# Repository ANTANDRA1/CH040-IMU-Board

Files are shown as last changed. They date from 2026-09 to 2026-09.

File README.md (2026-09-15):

ПЛАТА ДЛЯ IMU CH040

ОПИС ПРОЄКТУ

Проєкт являє собою односторонню друковану плату для підключення інерціального модуля CH040 IMU/VRU.

Плата розроблена в KiCad 10.

Основні завдання плати:

- встановлення модуля CH040;
- виведення всіх 18 контактів CH040 на гребінки Dupont з кроком 2.54 мм;
- додаткове виведення робочих інформаційних сигналів на роз'єм JST GH з кроком 1.25 мм;
- забезпечення живлення модуля;
- захист лінії живлення;
- монтажні отвори під гвинти М2.

CH040

CH040 — інерціальний модуль IMU/VRU.

Модуль підтримує UART та CAN-інтерфейси.

Для використання повноцінної CAN-шини необхідний зовнішній CAN-трансивер, оскільки CAN_TX та CAN_RX є логічними сигналами модуля, а не безпосередньо CANH та CANL.

Габарити модуля:

25 × 20 × 2.7 мм

РОЗ'ЄМ J1 — DUPONT 1×9, 2.54 ММ

1 — VDD
2 — GND
3 — EN
4 — IO1
5 — IO2
6 — RXD2
7 — TXD2
8 — GND
9 — IO5

РОЗ'ЄМ J2 — DUPONT 1×9, 2.54 ММ

1 — NRST
2 — RXD3
3 — TXD3
4 — CAN_TX
5 — CAN_RX
6 — IO9
7 — RXD1
8 — TXD1
9 — IO6

Таким чином, на J1 та J2 виведені всі 18 контактів CH040.

РОЗ'ЄМ J3 — JST GH 1×10, 1.25 ММ

На роз'єм J3 виведені робочі інформаційні та керуючі сигнали.

1 — EN
2 — IO1_EXT
3 — IO2_EXT
4 — IO5
5 — IO6
6 — UART1_TX
7 — UART1_RX
8 — CAN_TX
9 — CAN_RX
10 — NRST_EXT

Лінії IO1, IO2, TXD1, RXD1 та NRST підключені до J3 через послідовні резистори 1 кОм.

Контакти RXD2, TXD2, RXD3 та TXD3 не використовуються в поточній конфігурації CH040, а IO9 є зарезервованим, тому вони не дублюються на JST.

ЖИВЛЕННЯ

Живлення плати подається через роз'єм J4.

Робоча напруга:

3.3–5 В

Для захисту лінії живлення використані:

F1 — запобіжник 300 мА
D1 — TVS-діод SMF5.0CA

Схема живлення:

J4 → F1 → VDD → CH040

TVS-діод D1 підключений між VDD та GND.

ПЕРЕМИЧКА GND

Плата виконана односторонньою.

Контакт 8 модуля CH040 є контактом GND.

Через особливості одностороннього трасування його підключення до основної землі виконується через перемичку:

R6 — 0 Ом

Використовується вивідний THT-резистор, який фізично виконує функцію перемички над сигнальними доріжками.

ПОСАДКОВЕ МІСЦЕ CH040

Посадкове місце CH040 створене вручну відповідно до документації виробника.

Основні параметри:

габарит модуля — 25 × 20 мм
розмір контактної площадки — 1.4 × 1.2 мм
основний крок контактів — 2 мм

Під модулем створена спеціальна Keepout-зона.

У цій зоні заборонено:

- прокладати доріжки;
- розміщувати перехідні отвори;
- виконувати заливку міддю.

МОНТАЖ

На платі передбачено чотири монтажні отвори:

H1
H2
H3
H4

Отвори призначені для кріплення плати гвинтами М2.

ОСНОВНІ КОМПОНЕНТИ

U1 — CH040

J1, J2 — Dupont 1×9, 2.54 мм

J3 — JST GH 1×10, 1.25 мм

J4 — роз'єм живлення

R1–R5 — 1 кОм, корпус 0402

R6 — 0 Ом, THT

F1 — 300 мА

D1 — SMF5.0CA

H1–H4 — монтажні отвори М2

СТРУКТУРА ПРОЄКТУ

CH040

KiCad
    Ch040.kicad_pro
    Ch040.kicad_sch
    Ch040.kicad_pcb
    бібліотека символу CH040
    бібліотека посадкового місця CH040

Gerber & Drill
    Gerber-файли
    Drill-файли

Datasheet
    документація CH040

README.txt

ВІДТВОРЕННЯ ПРОЄКТУ

Для відкриття та редагування проєкту рекомендується використовувати KiCad 10.

1. Завантажити або клонувати репозиторій.

2. Відкрити файл Ch040.kicad_pro.

3. Перевірити підключення бібліотеки символу CH040 та бібліотеки його посадкового місця.

4. Відкрити принципову схему.

5. Відкрити PCB.

6. Запустити ERC для перевірки електричної схеми.

7. Запустити DRC для перевірки друкованої плати.

8. Для виробництва використовувати Gerber та Drill-файли з відповідної папки.

ПЕРЕВІРКА ПЛАТИ

Перед формуванням виробничих файлів виконано:

- ERC;
- DRC;
- перевірку нез'єднаних мереж;
- перевірку Keepout-зони CH040;
- перевірку плати у 3D Viewer;
- формування Gerber-файлів;
- формування Drill-файлів.

ПРИМІТКА

Проєкт виконаний відповідно до технічного завдання на розробку плати для IMU CH040.

Репозиторій містить принципову схему, PCB, користувацькі бібліотеки, Gerber-файли, файли свердління та документацію, необхідну для відтворення плати.

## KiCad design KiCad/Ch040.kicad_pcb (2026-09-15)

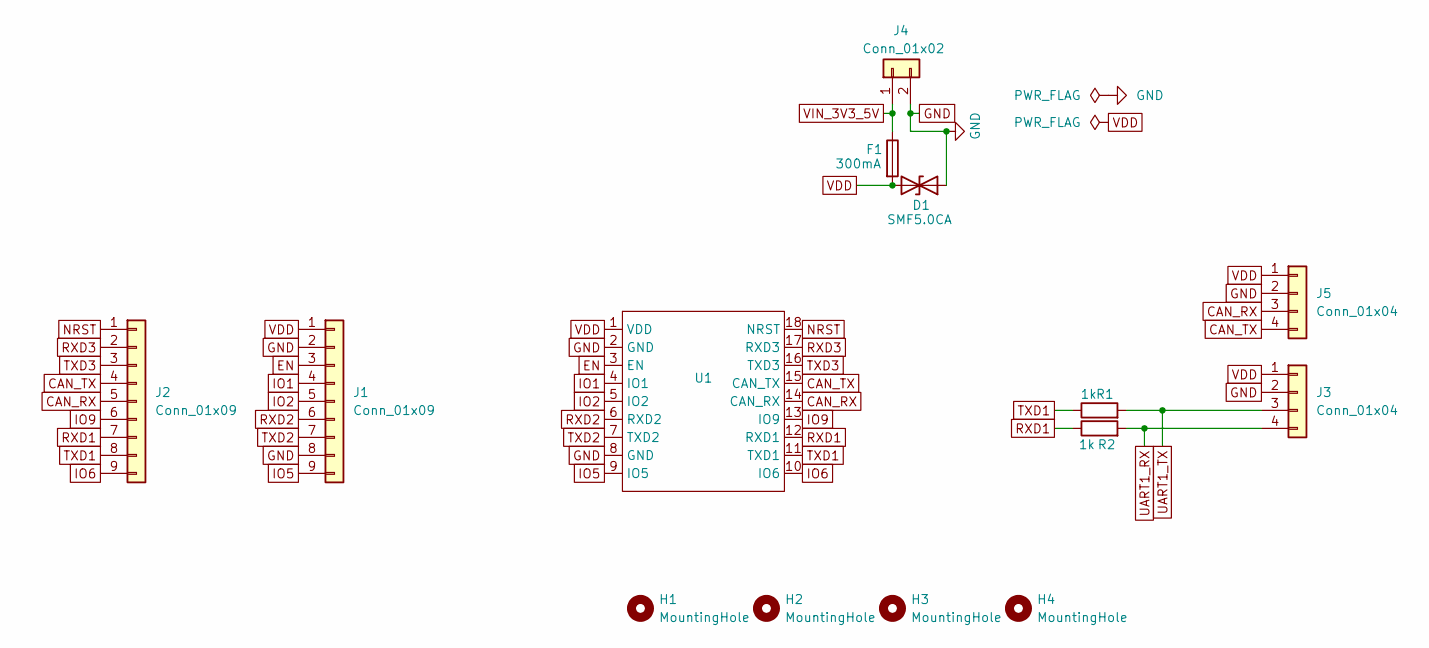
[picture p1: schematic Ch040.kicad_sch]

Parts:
D1: SMF5.0CA; D_SMA
F1: 300mA; Fuse_0603_1608Metric
H1, H2, H3, H4: MountingHole; MountingHole_2.2mm_M2
J1, J2: Conn_01x09; PinHeader_1x09_P2.54mm_Vertical
J3, J5: Conn_01x04; JST_GH_SM04B-GHS-TB_1x04-1MP_P1.25mm_Horizontal
J4: Conn_01x02; PinSocket_1x02_P2.54mm_Vertical
R1, R2: 1k; R_0805_2012Metric
U1: CH040

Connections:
CAN_RX: J2.5, J5.3, U1.14 (CAN_RX)
CAN_TX: J2.4, J5.4, U1.15 (CAN_TX)
EN: J1.3, U1.3 (EN)
GND: D1.1 (A1), J1.2, J1.8, J3.2, J4.2, J5.2, U1.2 (GND), U1.8 (GND)
IO1: J1.4, U1.4 (IO1)
IO2: J1.5, U1.5 (IO2)
IO5: J1.9, U1.9 (IO5)
IO6: J2.9, U1.10 (IO6)
IO9: J2.6, U1.13 (IO9)
NRST: J2.1, U1.18 (NRST)
RXD1: J2.7, R2.1, U1.12 (RXD1)
RXD2: J1.6, U1.6 (RXD2)
RXD3: J2.2, U1.17 (RXD3)
TXD1: J2.8, R1.1, U1.11 (TXD1)
TXD2: J1.7, U1.7 (TXD2)
TXD3: J2.3, U1.16 (TXD3)
UART1_RX: J3.4, R2.2
UART1_TX: J3.3, R1.2
VDD: D1.2 (A2), F1.2, J1.1, J3.1, J5.1, U1.1 (VDD)
VIN_3V3_5V: F1.1, J4.1

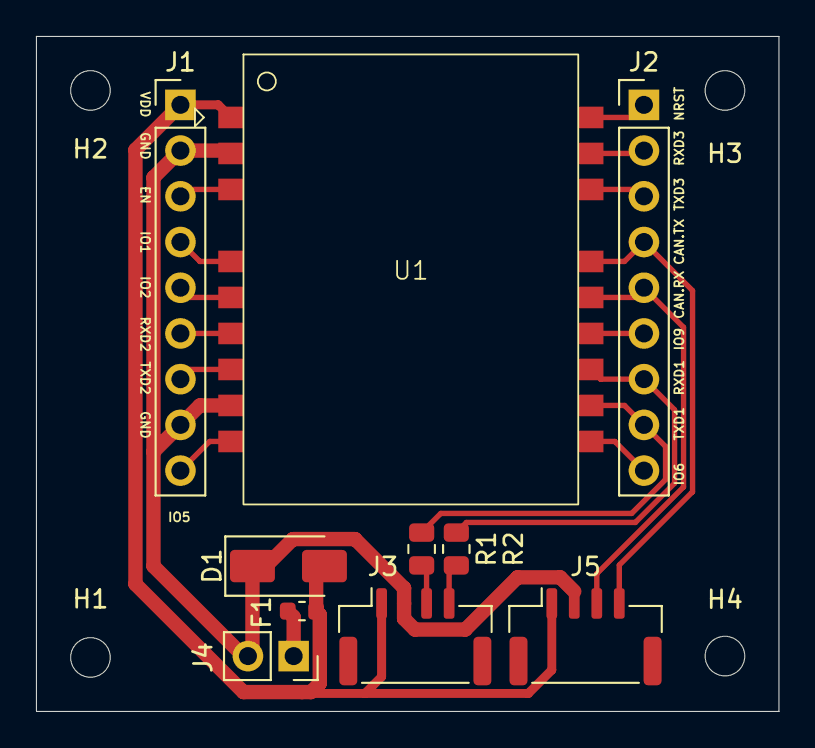
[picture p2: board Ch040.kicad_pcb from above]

Board: 2 copper layers, 41.2 x 37.5 mm, 14 parts (0 on the bottom side), 20 nets.
